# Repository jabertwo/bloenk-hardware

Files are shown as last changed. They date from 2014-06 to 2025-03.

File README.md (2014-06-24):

Blönk USB Notifier
=========
Schematics, PCB Layout and Windows Drivers

About
--
Blönk is an universal RGB light attached to the USB port. Originally designt as notifier for the Microsoft Lync software, Blönk now can be used for many other applications.

Flexibility
--
You can ether integrate Blönk into your own projects by using the .NET Library (or commandline software) or you can use Blönk with the already build software as Microsoft Lync notifier.

Software
--
You can find the sourcecode for the .NET library and software (also Lync integration) in a separate repository: https://github.com/johannes85/bloenk-software  
I also published more details about the project on my YouTube channel and website (in German): 
http://www.domestichacks.info/projekte/bloenk-usb-licht-fuer-lync/  
https://www.youtube.com/domestichacks

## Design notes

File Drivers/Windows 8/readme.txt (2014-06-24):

Unter Windows 8 kann der "libusb-win32" Treiber mit Hilfe von Zadig installiert werden.
Das deaktivieren der Treibersignatur Überprüfung ist hierfür nicht notwendig.

Anleitung:
	Blönk einstecken
	Zadig starten
	"Bloenk" in dem Dropdown Feld auswählen
	In dem Feld rechts neben dem "Driver" Feld "libusb-win32" auswählen
	Auf "Install Driver" klicken

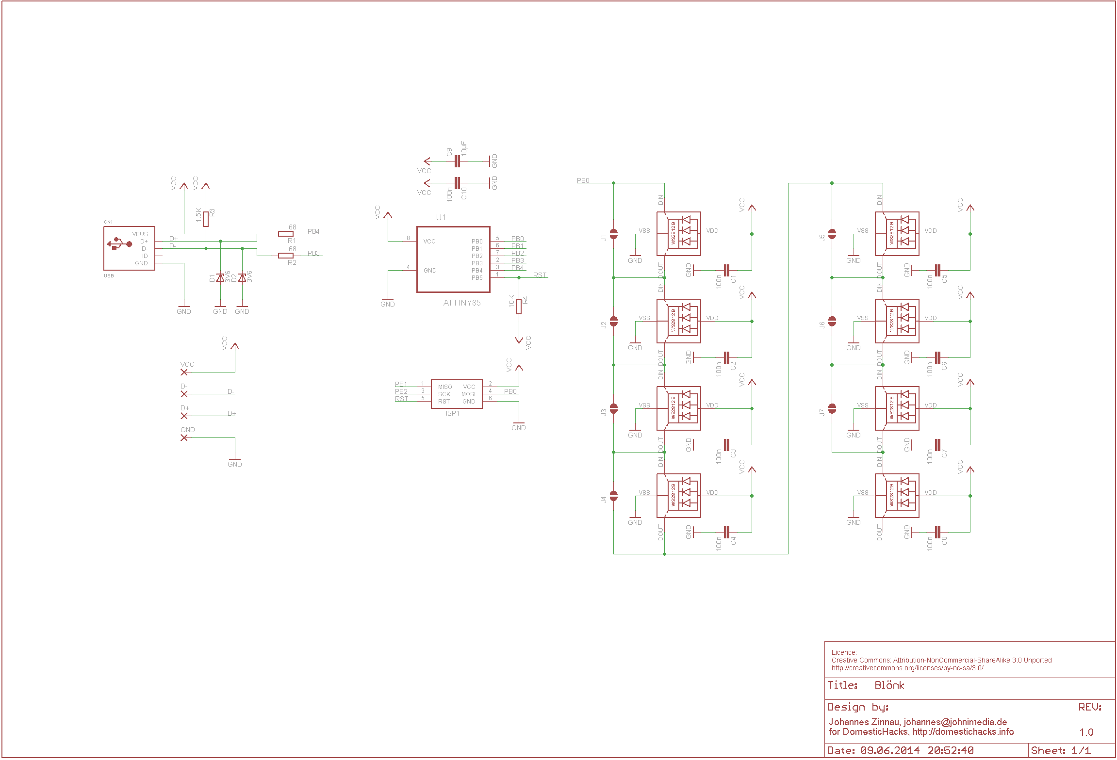
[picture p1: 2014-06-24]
Schematics/1.0/schematics.png

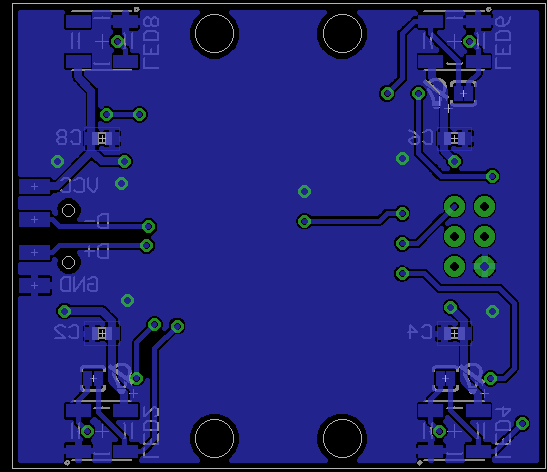
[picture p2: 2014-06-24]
Schematics/1.0/bottom.png

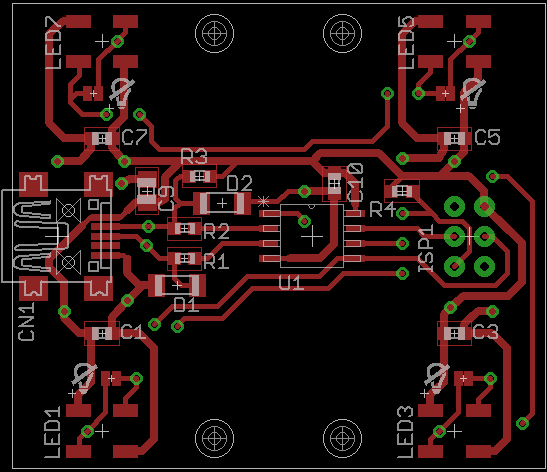
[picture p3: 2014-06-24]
Schematics/1.0/top.png

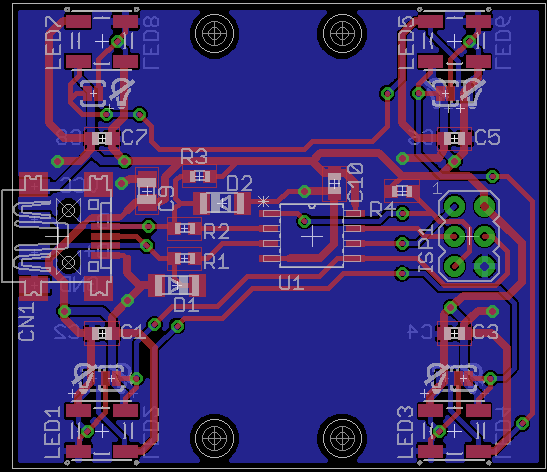
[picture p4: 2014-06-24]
Schematics/1.0/bothlayers.png

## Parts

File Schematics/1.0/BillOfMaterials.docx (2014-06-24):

# Blönk

# Bill of Materials

Bauteil | Bezeichnung | Anzahl | Quelle | Artikelnummer
U1 | ATtiny85-20SU | 1 | http://www.reichelt.de | ATTINY 85-20 SU
D1, D1 | Zener Diode 0,5W 3,6V – SOD 80 | 2 | http://www.reichelt.de | SMD ZF 3,6
CN1 | USB-Einbaubuchse – B-Mini gewinkelt | 1 | http://www.reichelt.de | USB BWM SMD
LED1 - 8 | WS2812B RGB LED mit eingebautem Controller | 8* | http://www.ebay.de
R1, R2 | SMD Widerstand 68 Ohm – 0603, 1% | 2 | http://www.reichelt.de | SMD-0603 68
R3 | SMD Widerstand 1,5 kOhm – 0603, 1% | 1 | http://www.reichelt.de | SMD-0603 1,5K
R4 | SMD Widerstand 10 kOhm – 0603, 1% | 1 | http://www.reichelt.de | SMD-0603 10K
C1 – 8, C10 | SMD Vielschicht-Keramikkondensator 100N 16V – 0603, X7R, 10% | 8 | http://www.reichelt.de | X7R-G0603 100N
C9 | SMD Vielschicht-Keramikkondensator 10µF 16V – 0805, X5R, 15% | 1 | http://www.reichelt.de | X5R-G0805 10/16
ISP1 | Stiftleiste 2x3‐pol – RM 2,54 | 1 | http://www.reichelt.de | MPE 087-2-006

* Die Anzahl der LEDs kann je nach Anwendungszweck variieren. Es können bis zu 8 LEDs montiert werden (gute Kühlung vorausgesetzt).

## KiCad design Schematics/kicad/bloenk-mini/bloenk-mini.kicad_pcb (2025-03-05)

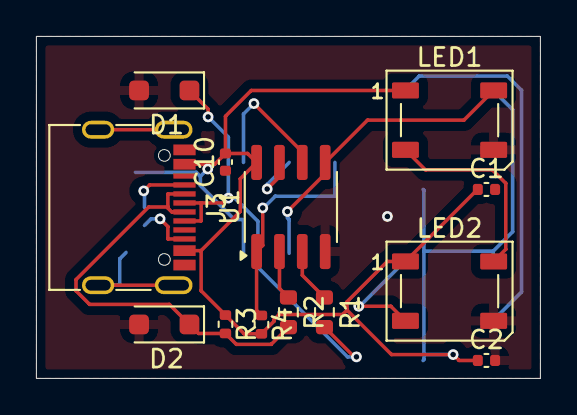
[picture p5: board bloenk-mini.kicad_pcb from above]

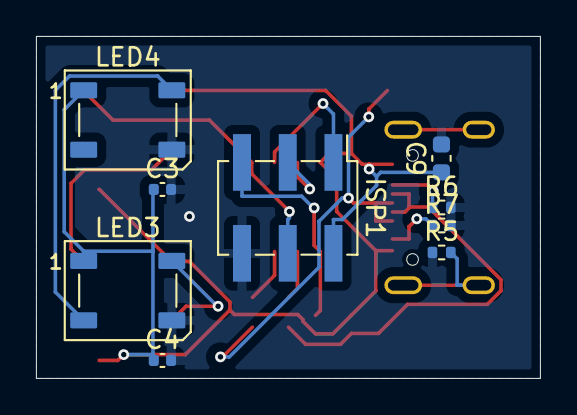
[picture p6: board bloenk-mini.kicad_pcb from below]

Board: 2 copper layers, 28.0 x 19.0 mm, 22 parts (9 on the bottom side), 16 nets.

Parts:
C1, C2, C3, C4, C10: 100n; C_0402_1005Metric
C9: 10µF; C_0603_1608Metric
D1, D2: 3V6; D_SOD-123F
ISP1: AVRISP-6; PinHeader_2x03_P2.54mm_Vertical_SMD
J3: USB_C_Receptacle_USB2.0_16P; USB_C_Receptacle_G-Switch_GT-USB-7010ASV
LED1, LED2, LED3, LED4: WS2812B; LED_WS2812B_PLCC4_5.0x5.0mm_P3.2mm
R1, R2: 75; R_0603_1608Metric
R3: 1.5K; R_0402_1005Metric
R4: 10K; R_0402_1005Metric
R5: 1M; R_0402_1005Metric
R6, R7: 5.11k; R_0402_1005Metric
U1: ATTINY85; SOIC-8_3.9x4.9mm_P1.27mm

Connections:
/D+: D1.1, J3.A6 (D+), J3.B6 (D+), R1.2
/D-: D2.1, J3.A7 (D-), J3.B7 (D-), R2.2, R3.2
/PB0: ISP1.4 (MOSI), LED1.4, U1.5 (PB0)
/PB1: ISP1.1 (MISO), U1.6 (PB1)
/PB2: ISP1.3 (SCK), U1.7 (PB2)
/PB3: R2.1, U1.2 (PB3)
/PB4: R1.1, U1.3 (PB4)
/RST: ISP1.5 (RST), R4.1, U1.1 (PB5)
GND: C1.2, C2.2, C3.2, C4.2, C9.2, C10.1, D1.2, D2.2, ISP1.6 (GND), J3.A1 (GND), J3.A12 (GND), J3.B1 (GND), J3.B12 (GND), LED1.3, LED2.3, LED3.3, LED4.3, R5.1, R6.2, R7.2, U1.4 (GND)
unnamed: J3.A5 (CC1), R6.1
unnamed: J3.B5 (CC2), R7.1
unnamed: J3.S1 (SHIELD), R5.2
VCC: C1.1, C2.1, C3.1, C4.1, C9.1, C10.2, ISP1.2 (VCC), J3.A4 (VBUS), J3.A9 (VBUS), J3.B4 (VBUS), J3.B9 (VBUS), LED1.1, LED2.1, LED3.1, LED4.1, R3.1, R4.2, U1.8 (VCC)
WS-1: LED1.2, LED2.4
WS-2: LED2.2, LED3.4
WS-3: LED3.2, LED4.4

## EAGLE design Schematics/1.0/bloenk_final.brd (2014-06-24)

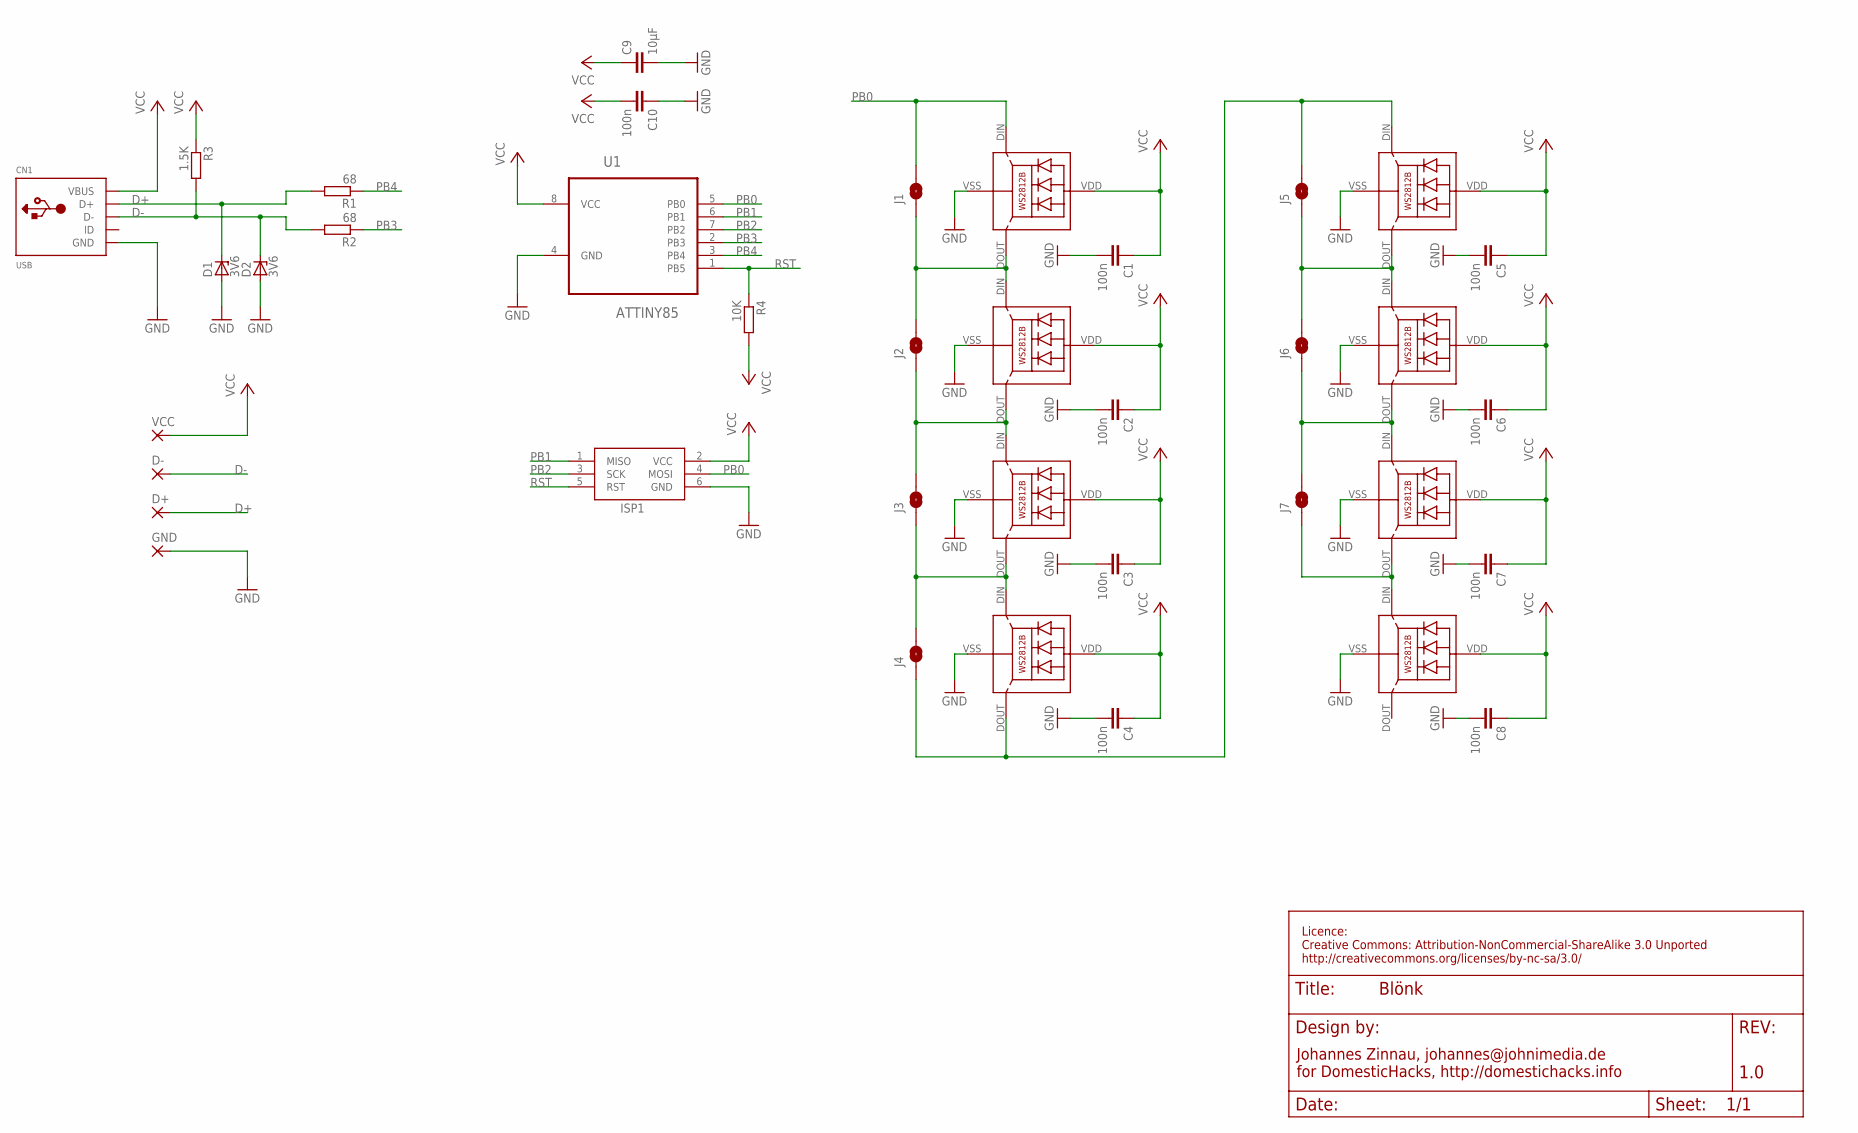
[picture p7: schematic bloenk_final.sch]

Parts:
C1, C2, C3, C4, C5, C6, C7, C8, C10: 100n; C0603
C9: 10µF; C0805
CN1: USB; USB-MINIB
D1, D2: 3V6; SOD80C
D+: SMD2; SMD1,27-2,54
D-: SMD2; SMD1,27-2,54
GND: SMD2; SMD1,27-2,54
ISP1: AVRISP-6; AVRISP
J1, J2, J3, J4, J5, J6, J7: SOLDERJUMPERNO; SJ_2S-NO
LED1, LED2, LED3, LED4, LED5, LED6, LED7, LED8: WS2812B
R1, R2: 68; R0603
R3: 1.5K; R0603
R4: 10K; R0603
U1: ATTINY85; SOIC127P798X216-8N
VCC: SMD2; SMD1,27-2,54

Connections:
D+: CN1.D+, D1.C, D+.1, R1.2
D-: CN1.D-, D2.C, D-.1, R2.2, R3.2
GND: C1.2, C2.2, C3.2, C4.2, C5.2, C6.2, C7.2, C8.2, C9.2, C10.1, CN1.GND, D1.A, D2.A, GND.1, ISP1.6 (GND), LED1.VSS (GND), LED2.VSS (GND), LED3.VSS (GND), LED4.VSS (GND), LED5.VSS (GND), LED6.VSS (GND), LED7.VSS (GND), LED8.VSS (GND), U1.4 (GND)
unnamed: J2.1, J3.2, LED2.DOUT (DO), LED3.DIN (DI)
unnamed: J3.1, J4.2, LED3.DOUT (DO), LED4.DIN (DI)
unnamed: J1.1, J2.2, LED1.DOUT (DO), LED2.DIN (DI)
unnamed: J5.1, J6.2, LED5.DOUT (DO), LED6.DIN (DI)
unnamed: J6.1, J7.2, LED6.DOUT (DO), LED7.DIN (DI)
unnamed: J7.1, LED7.DOUT (DO), LED8.DIN (DI)
unnamed: J4.1, J5.2, LED4.DOUT (DO), LED5.DIN (DI)
PB0: ISP1.4 (MOSI), J1.2, LED1.DIN (DI), U1.5 (PB0)
PB1: ISP1.1 (MISO), U1.6 (PB1)
PB2: ISP1.3 (SCK), U1.7 (PB2)
PB3: R2.1, U1.2 (PB3)
PB4: R1.1, U1.3 (PB4)
RST: ISP1.5 (RST), R4.1, U1.1 (PB5)
VCC: C1.1, C2.1, C3.1, C4.1, C5.1, C6.1, C7.1, C8.1, C9.1, C10.2, CN1.VBUS, ISP1.2 (VCC), LED1.VDD, LED2.VDD, LED3.VDD, LED4.VDD, LED5.VDD, LED6.VDD, LED7.VDD, LED8.VDD, R3.1, R4.2, U1.8 (VCC), VCC.1

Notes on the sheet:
Johannes Zinnau, johannes@johnimedia.de for DomesticHacks, http://domestichacks.info
1.0
Licence: Creative Commons: Attribution-NonCommercial-ShareAlike 3.0 Unported http://creativecommons.org/licenses/by-nc-sa/3.0/

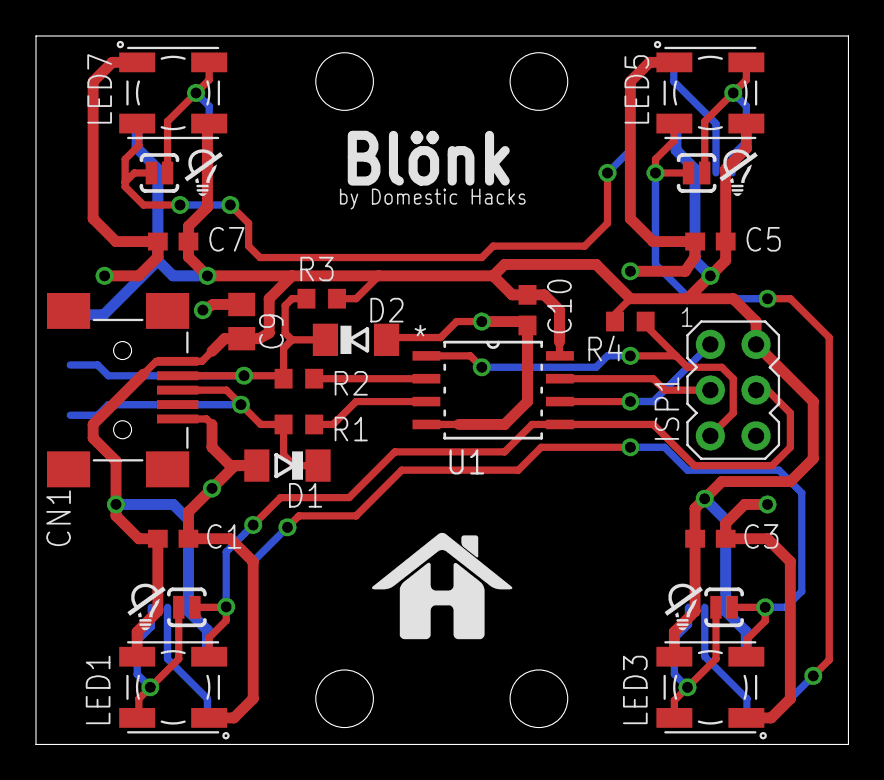
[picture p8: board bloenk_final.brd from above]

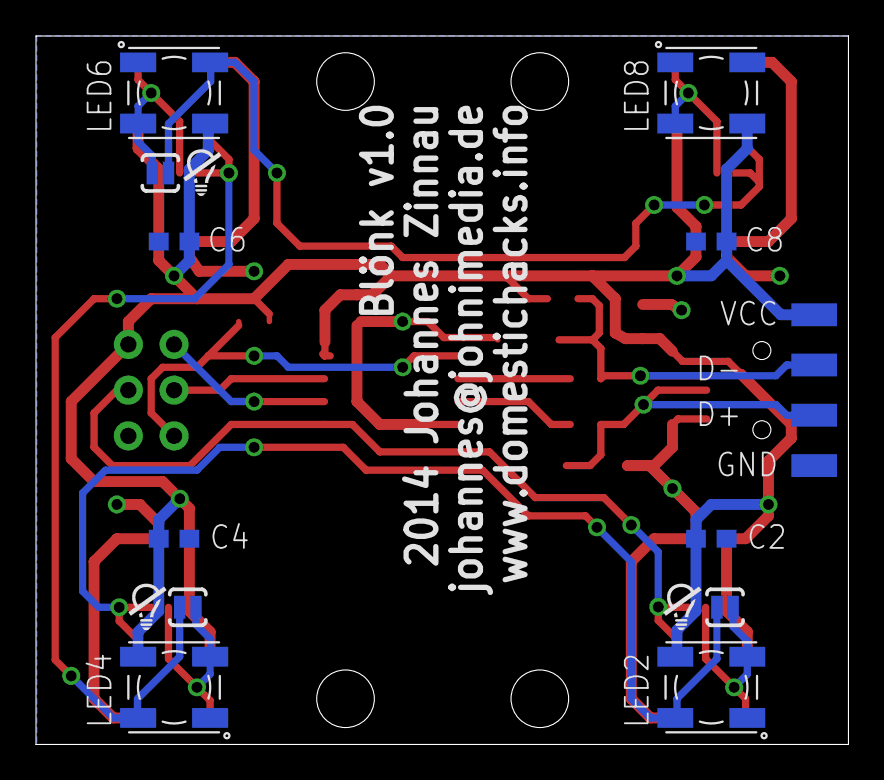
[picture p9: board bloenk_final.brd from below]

Board: 2 copper layers, 45.1 x 39.4 mm, 46 parts (18 on the bottom side), 17 nets.

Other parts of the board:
U$1, U$2, U$3, U$4, U$5, U$6, U$7: BULB
U$9: DH

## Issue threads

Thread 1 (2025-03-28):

footprint for attiny is wrong

jabertwo, 2025-03-28:
The footprint for the attiny is too small

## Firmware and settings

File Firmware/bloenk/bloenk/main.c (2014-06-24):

/*
 *   ____  _ _   _       _    
 *  |  _ \| (_) (_)     | |   
 *  | |_) | | ___  _ __ | | __
 *  |  _ <| |/ _ \| '_ \| |/ /
 *  | |_) | | (_) | | | |   < 
 *  |____/|_|\___/|_| |_|_|\_\    
 * 
 *   Blönk Firmware     
 *   v0.2
 *  
 * by DomesticHacks
 * http://www.domestichacks.info/
 * http://www.youtube.com/DomesticHacks
 *
 * Author: Johannes Zinnau (johannes@johnimedia.de)
 * 
 * License:
 * GNU GPL v2
 *
 * Based on: VUSB hid-custom-rq example
 *  Name: main.c
 *  Project: hid-custom-rq example
 *  Author: Christian Starkjohann
 *  Creation Date: 2008-04-07
 *  Tabsize: 4
 *  Copyright: (c) 2008 by OBJECTIVE DEVELOPMENT Software GmbH
 *  License: GNU GPL v2 (see License.txt), GNU GPL v3 or proprietary (CommercialLicense.txt)
 */

#define LED_PORT_DDR        DDRB
#define LED_PORT_OUTPUT     PORTB
#define LED_BIT             0
#define LED_DEFAULT_COUNT	8

#define abs(x) ((x) > 0 ? (x) : (-x))

#include <avr/io.h>
#include <avr/wdt.h>
#include <avr/eeprom.h>
#include <avr/interrupt.h>
#include <util/delay.h>

#include <avr/pgmspace.h>
#include "usbconfig.h"
#include "usbdrv/usbdrv.h"
#include "requests.h"
#include "light_ws2812/light_ws2812.h"

uint8_t eeCalibrationMemory EEMEM = 0;
uint8_t eeLedCountMemory EEMEM = 1;
struct CRGB { uint8_t g; uint8_t r; uint8_t b; };
struct CRGB led[254];
uint8_t currentLed;
uint8_t ledCount;
static uchar replyBuffer[1];

void setLedColor(uint8_t ledNum, uint8_t r, uint8_t g, uint8_t b)
{
	led[ledNum].r = r;
	led[ledNum].g = g;
	led[ledNum].b = b;
}

void writeToLeds()
{
	uint8_t i;

	cli();
	for (i=0; i<ledCount; i++) {
		ws2812_sendarray((uint8_t *)&led[i],3);
	}
	sei();
	
	_delay_us(50);
}

void setLedCount(uint8_t count)
{
	if(count > 0 && count < 254){
		ledCount = count;
		if(currentLed >= count){
			currentLed = 0;
		}
		eeprom_update_byte(&eeLedCountMemory, count);
	}
}

usbMsgLen_t usbFunctionSetup(uchar data[8])
{
    uint8_t returnLen = 0;
	usbRequest_t    *rq = (void *)data;
    if((rq->bmRequestType & USBRQ_TYPE_MASK) == USBRQ_TYPE_VENDOR){
        if(rq->bRequest == CUSTOM_RQ_SET_CURRENT_LED){
			if (rq->wValue.bytes[0] < ledCount) {
				currentLed = rq->wValue.bytes[0];
			}
        }
        
        if(rq->bRequest == CUSTOM_RQ_SET_COLOR_R){
          led[currentLed].r = rq->wValue.bytes[0];
        }
        
        if(rq->bRequest == CUSTOM_RQ_SET_COLOR_G){
          led[currentLed].g = rq->wValue.bytes[0];
        }
        
        if(rq->bRequest == CUSTOM_RQ_SET_COLOR_B){
          led[currentLed].b = rq->wValue.bytes[0];
        }
        
        if(rq->bRequest == CUSTOM_RQ_WRITE_TO_LEDS){
          writeToLeds();
        }
        
        if(rq->bRequest == CUSTOM_RQ_SET_LEDCOUNT){
          setLedCount(rq->wValue.bytes[0]);
        }
        
        if(rq->bRequest == CUSTOM_RQ_GET_LEDCOUNT){
          replyBuffer[0] = ledCount;
          usbMsgPtr = replyBuffer;
          returnLen = 1;
        }
    }
    return returnLen;
}

static void calibrateOscillator(void)
{
	uchar       step = 128;
	uchar       trialValue = 0, optimumValue;
	int         x, optimumDev, targetValue = (unsigned)(1499 * (double)F_CPU / 10.5e6 + 0.5);

    /* do a binary search: */
    do{
        OSCCAL = trialValue + step;
        x = usbMeasureFrameLength();    /* proportional to current real frequency */
        if(x < targetValue)             /* frequency still too low */
            trialValue += step;
        step >>= 1;
    }while(step > 0);
    /* We have a precision of +/- 1 for optimum OSCCAL here */
    /* now do a neighborhood search for optimum value */
    optimumValue = trialValue;
    optimumDev = x; /* this is certainly far away from optimum */
    for(OSCCAL = trialValue - 1; OSCCAL <= trialValue + 1; OSCCAL++){
        x = usbMeasureFrameLength() - targetValue;
        if(x < 0)
            x = -x;
        if(x < optimumDev){
            optimumDev = x;
            optimumValue = OSCCAL;
        }
    }
    OSCCAL = optimumValue;
}

void hadUsbReset(void)
{
    cli(); // usbMeasureFrameLength() counts CPU cycles, so disable interrupts.
    calibrateOscillator();
    sei();
    eeprom_update_byte(&eeCalibrationMemory, OSCCAL);   /* store the calibrated value in EEPROM */
}

int __attribute__((noreturn)) main(void)
{
	uchar   i;

	// Read oscillator calibration
	uchar   calibrationValue;
	calibrationValue = eeprom_read_byte(&eeCalibrationMemory); /* calibration value from last time */
    if(calibrationValue != 0xff){
        OSCCAL = calibrationValue;
    }
	
    wdt_enable(WDTO_1S);
	
	// Init USB
    usbInit();
    usbDeviceDisconnect();  /* enforce re-enumeration, do this while interrupts are disabled! */
    i = 0;
    while(--i){             /* fake USB disconnect for > 250 ms */
        wdt_reset();
        _delay_ms(1);
    }
    usbDeviceConnect();
    sei();
	
	// Read led count configuration
	ledCount = eeprom_read_byte(&eeLedCountMemory);
	if(ledCount == 0xff){
		ledCount = LED_DEFAULT_COUNT;
	}
	
	// Init leds
	currentLed = 0;
	LED_PORT_DDR |= 1 << LED_BIT;
	for (i=0; i<ledCount; i++) {
		setLedColor(i, 0, 30, 0);
	}
	writeToLeds();
	
	// Main loop
    for(;;){
        wdt_reset();
        usbPoll();
    }
}

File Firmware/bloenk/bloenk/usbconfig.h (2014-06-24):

/* Name: usbconfig.h
 * Project: V-USB, virtual USB port for Atmel's(r) AVR(r) microcontrollers
 * Author: Christian Starkjohann
 * Creation Date: 2005-04-01
 * Tabsize: 4
 * Copyright: (c) 2005 by OBJECTIVE DEVELOPMENT Software GmbH
 * License: GNU GPL v2 (see License.txt), GNU GPL v3 or proprietary (CommercialLicense.txt)
 */

#ifndef __usbconfig_h_included__
#define __usbconfig_h_included__

/*
General Description:
This file is an example configuration (with inline documentation) for the USB
driver. It configures V-USB for USB D+ connected to Port D bit 2 (which is
also hardware interrupt 0 on many devices) and USB D- to Port D bit 4. You may
wire the lines to any other port, as long as D+ is also wired to INT0 (or any
other hardware interrupt, as long as it is the highest level interrupt, see
section at the end of this file).
*/

/* ---------------------------- Hardware Config ---------------------------- */

#define USB_CFG_IOPORTNAME      B
/* This is the port where the USB bus is connected. When you configure it to
 * "B", the registers PORTB, PINB and DDRB will be used.
 */
#define USB_CFG_DMINUS_BIT      3
/* This is the bit number in USB_CFG_IOPORT where the USB D- line is connected.
 * This may be any bit in the port.
 */
#define USB_CFG_DPLUS_BIT       4
/* This is the bit number in USB_CFG_IOPORT where the USB D+ line is connected.
 * This may be any bit in the port. Please note that D+ must also be connected
 * to interrupt pin INT0! [You can also use other interrupts, see section
 * "Optional MCU Description" below, or you can connect D- to the interrupt, as
 * it is required if you use the USB_COUNT_SOF feature. If you use D- for the
 * interrupt, the USB interrupt will also be triggered at Start-Of-Frame
 * markers every millisecond.]
 */
#define USB_CFG_CLOCK_KHZ       (F_CPU/1000)
/* Clock rate of the AVR in kHz. Legal values are 12000, 12800, 15000, 16000,
 * 16500, 18000 and 20000. The 12.8 MHz and 16.5 MHz versions of the code
 * require no crystal, they tolerate +/- 1% deviation from the nominal
 * frequency. All other rates require a precision of 2000 ppm and thus a
 * crystal!
 * Since F_CPU should be defined to your actual clock rate anyway, you should
 * not need to modify this setting.
 */
#define USB_CFG_CHECK_CRC       0
/* Define this to 1 if you want that the driver checks integrity of incoming
 * data packets (CRC checks). CRC checks cost quite a bit of code size and are
 * currently only available for 18 MHz crystal clock. You must choose
 * USB_CFG_CLOCK_KHZ = 18000 if you enable this option.
 */

/* ----------------------- Optional Hardware Config ------------------------ */

/* #define USB_CFG_PULLUP_IOPORTNAME   D */
/* If you connect the 1.5k pullup resistor from D- to a port pin instead of
 * V+, you can connect and disconnect the device from firmware by calling
 * the macros usbDeviceConnect() and usbDeviceDisconnect() (see usbdrv.h).
 * This constant defines the port on which the pullup resistor is connected.
 */
/* #define USB_CFG_PULLUP_BIT          4 */
/* This constant defines the bit number in USB_CFG_PULLUP_IOPORT (defined
 * above) where the 1.5k pullup resistor is connected. See description
 * above for details.
 */

/* --------------------------- Functional Range ---------------------------- */
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

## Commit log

2014-06-24 Initial release
    [bloenk_final.brd, bloenk_final.sch]
2025-03-05 WIP new kicad version of pcb with usb type c
    [bloenk-mini.dsn, bloenk-mini.kicad_pcb, bloenk-mini.kicad_sch]

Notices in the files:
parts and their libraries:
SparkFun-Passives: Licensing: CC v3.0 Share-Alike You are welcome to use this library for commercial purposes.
